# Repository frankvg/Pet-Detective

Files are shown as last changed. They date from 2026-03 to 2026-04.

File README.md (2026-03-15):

Pet Detective monitors pet movement in and out of a pet door, records the action, and logs the time. It uses an ESP32 processor with a Time-of-Flight laser sensor. The software is mostly C++ for Arduino, along with some HTML and JavaScript. See the PDF file for full details and additional software development notes. 
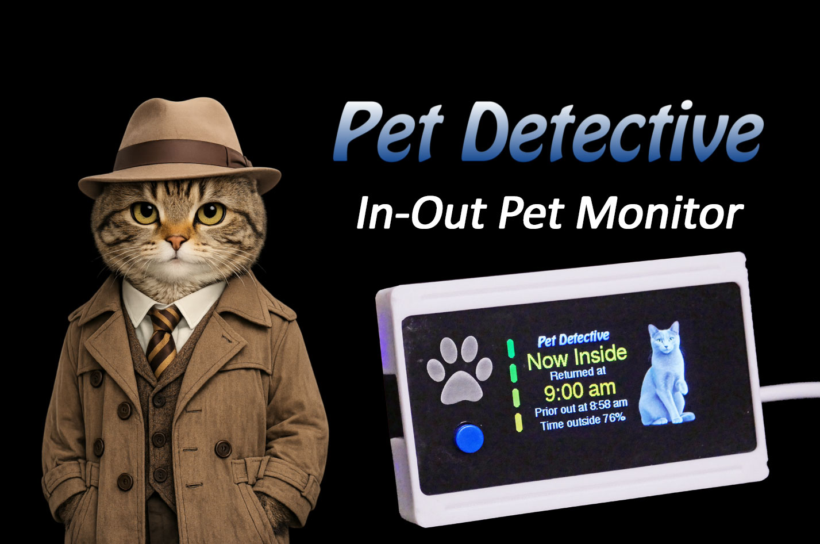
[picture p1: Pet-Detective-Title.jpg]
Model


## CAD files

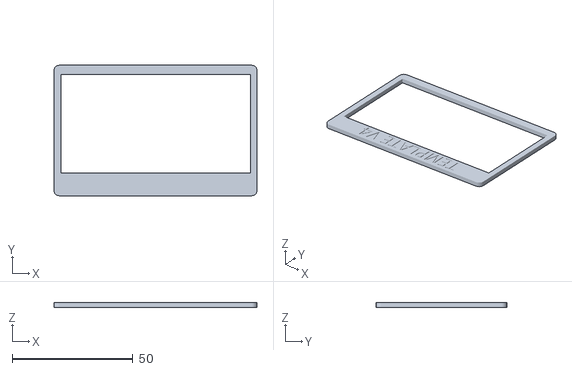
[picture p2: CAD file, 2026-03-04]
3D STL Print Files/Pet Detective Lens Template V4.stl
84.0 x 54.0 x 2.00

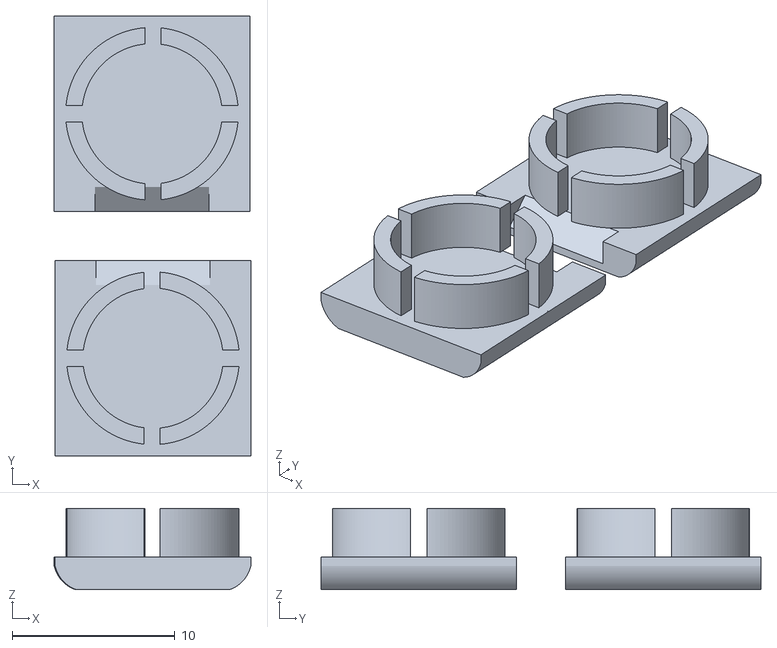
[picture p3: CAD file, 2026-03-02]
3D STL Print Files/Pet Detective HiTech Plug V2.stl
12.1 x 27.0 x 5.00

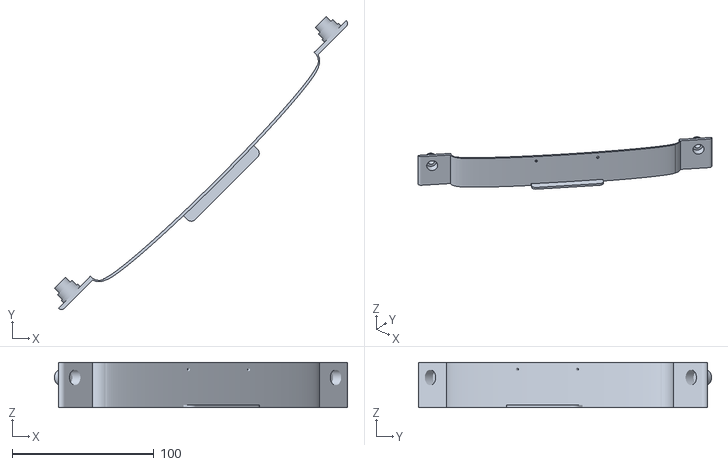
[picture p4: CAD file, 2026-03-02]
3D STL Print Files/Pet Detective HiTech Bracket V3.stl
206.5 x 206.5 x 32.0

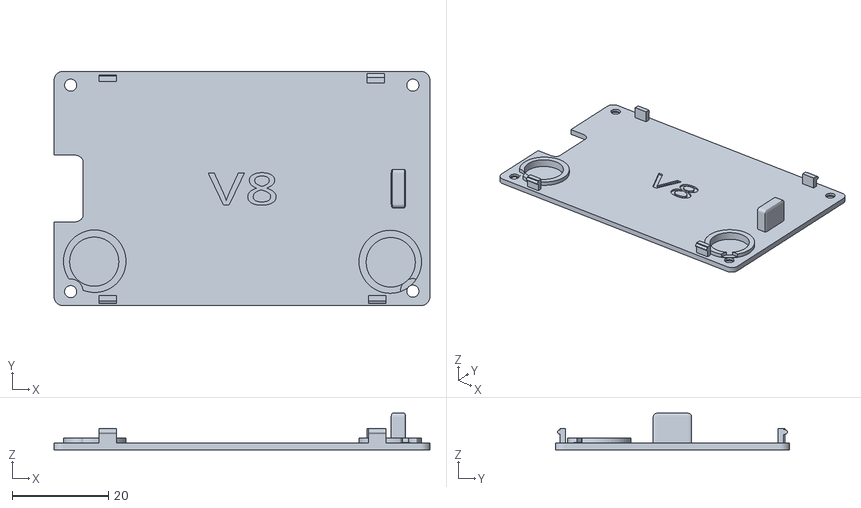
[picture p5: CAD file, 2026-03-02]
3D STL Print Files/Pet Detective Case Back V8.stl
78.1 x 48.7 x 7.60

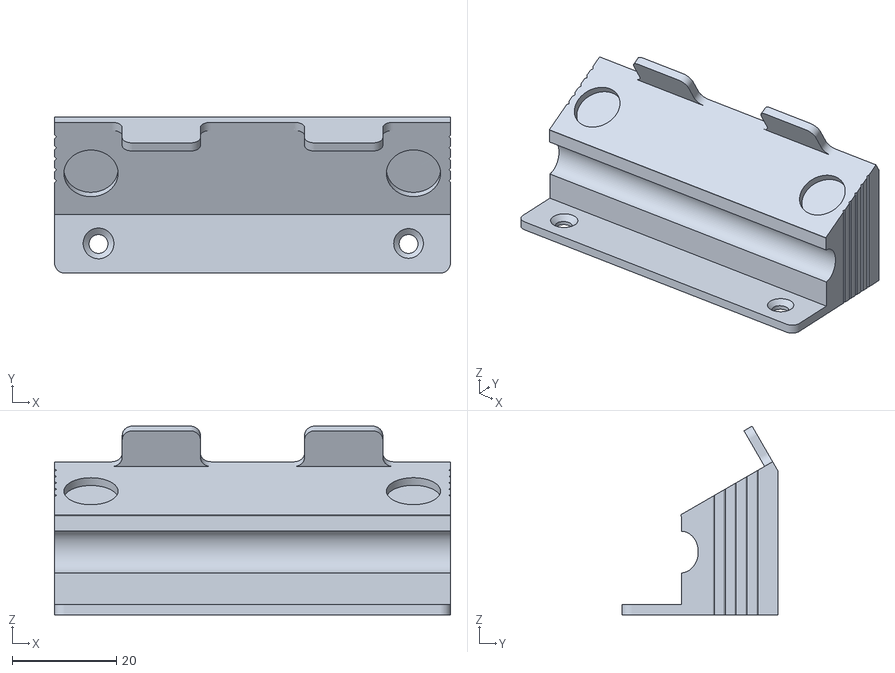
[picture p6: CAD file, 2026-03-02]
3D STL Print Files/Pet DetectiveMounting V5.stl
76.0 x 30.0 x 36.2

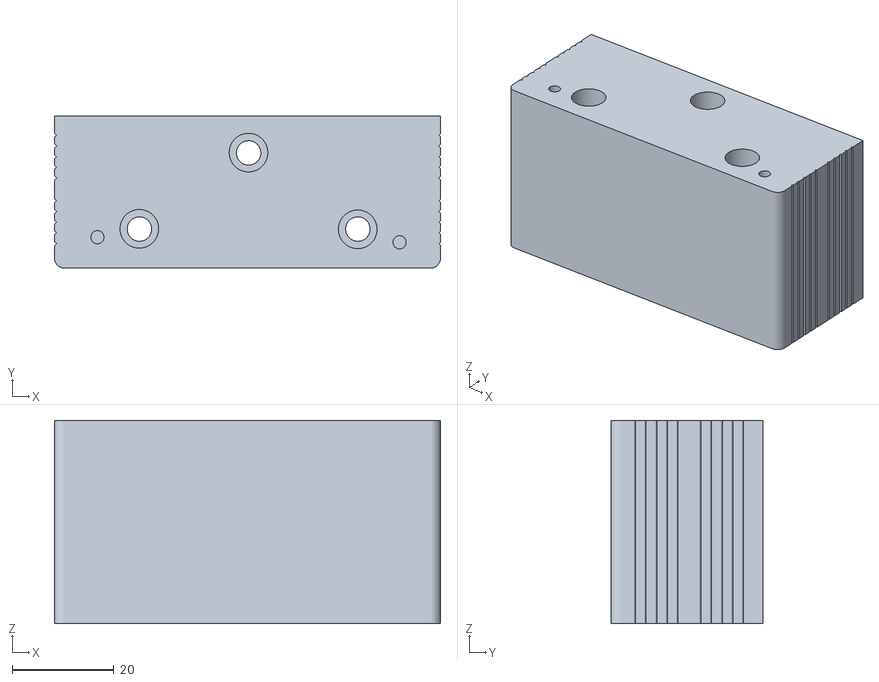
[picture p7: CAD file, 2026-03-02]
3D STL Print Files/Pet Detective Standoff V2.stl
76.0 x 30.0 x 40.0

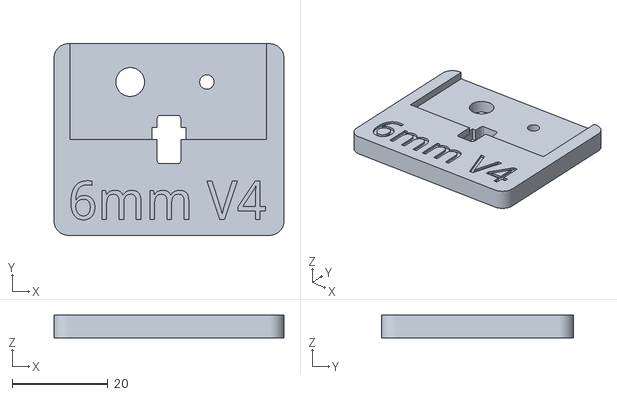
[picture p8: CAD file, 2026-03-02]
3D STL Print Files/Pet Detective Hole Tempate V4.stl
48.0 x 40.0 x 4.80

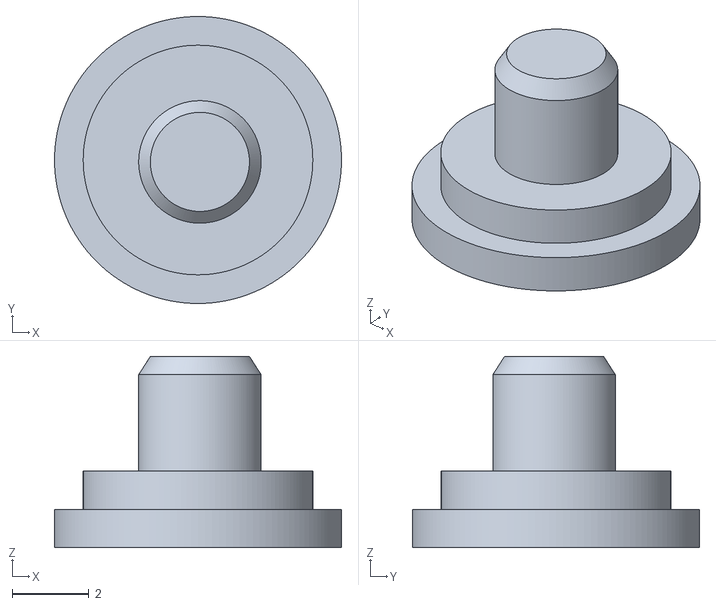
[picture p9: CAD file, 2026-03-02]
3D STL Print Files/Pet Detective Button Bottom V2.stl
7.50 x 7.50 x 5.00

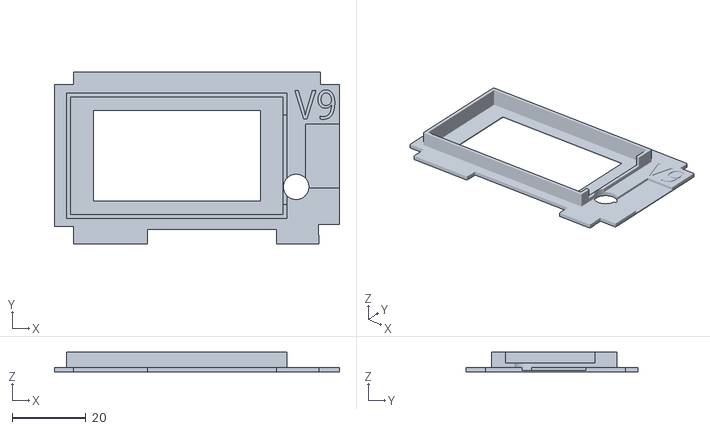
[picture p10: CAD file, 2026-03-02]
3D STL Print Files/Pet Detective Blackout V9.stl
77.4 x 46.6 x 5.40

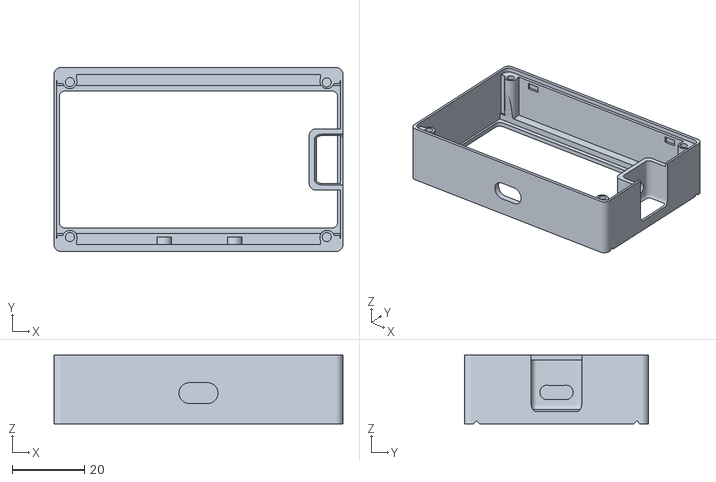
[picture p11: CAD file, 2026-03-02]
3D STL Print Files/Pet Detective Case Front V6.stl
80.0 x 51.0 x 19.0

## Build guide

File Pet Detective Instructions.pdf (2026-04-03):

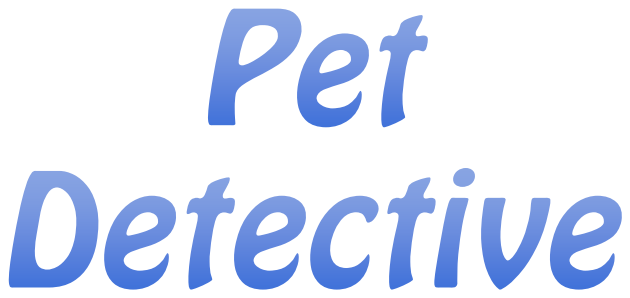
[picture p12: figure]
Pet Detective

Pet Detective tracks your pet’s movement in and out of a pet door. The time your pet goes in or out displays on the monitor and time stamped in a log. The information appears on the unit’s 1.9” LCD monitor.

WiFi is used to get the time and maintain time accurately. Using WiFi, Pet Detective can also display your pet’s status on a browser running on your local network.

## Features

- Location of pet, inside or outside, with time of occurrence
- Percent of time spent outside vs. inside
- View of instant sensor status
- Log of last 32 pet movement directions with a date/time stamp
- WiFi Status and WiFi Reset option
- Automatic time set, even after power failure or DST change
- View the status and log via browser on your local network
- Sensor calibration and distance monitor
- 12 or 24-hour mode selection
- Time Zone setting for 7 North America zones and DST options
- Choice of colors for Inside and Outside status: Green, Blue or Amber
- Select a set of Cat or Dog images

## Video

Video of Pet Detective in action: https://youtu.be/zv0K4LfRqQs

## Skills Needed

This is a rather complex project, but we have done all the hard work in design! You will need to be able to print 3D parts; make or buy the cover lens; solder a few wires; perform simple mechanical assembly; install the software; mount the unit above your pet door; and enjoy!

## Parts List

These are the project parts. You may have parts already in your collection or find other sources for the parts. Substituting alternative parts may require changing the case design or software. Links are for sources we use, but we have no affiliation with any of these vendors. We also made a partial kit of parts to save time and money. Prices were as of April 2026.
Electrical Parts
- ESP32 Dev Module, includes 1.9” LCD display ($16) https://www.amazon.com/dp/B0D6QXC813

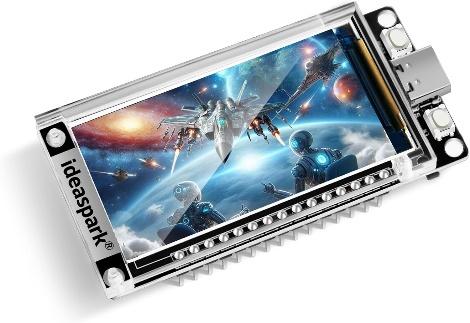
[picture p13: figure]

- VL53L5X V2 8x8 Wide Angle Time-of-Flight Laser sensor module ($17-19) https://www.walmart.com/ip/8565454261 OR https://www.amazon.com/QERPON-Multiple-VL53L5CX-Distance-Measuring/dp/B0F1TFWVNL (https://www.amazon.com/QERPON-Multiple-VL53L5CX-Distance-Measuring/dp/B0F1TFWVNL)
- 180-degree USB C adapter https://www.amazon.com/dp/B0BRFZHJVW ($7 for 2-pack, optional)
- USB C cable (any data cable should work)
- USB power adapter (It requires less than 10 mA, so any adapter will work)
OR
USB Power bank battery – This unit requires so little power, a 7500 mA power bank should power Pet Detective for a month before you’d need to recharge it.

Other Parts

- Hard plastic button (optional, see text, included in parts kit)
- 4 – 10mm diameter x 1mm magnets https://www.amazon.com/dp/B0CZ94J8BS ($8 for 100 magnets)
- 6 – M2.3 x 4mm Flat head self tapping screws (M2.5 x 4 mm ok as well)
- 2 –M3 x 8 mm flat head wood screws (for mounting bracket)
- 2 - M4 x 50 mm round-head wood screws (for optional extended mount to door)
- 1 - Male/Female connector pair with wires (optional, $8 for 10 pairs) https://www.amazon.com/dp/B0DNTK1S9L
OR
4 - 3” (8 mm) 26-28 gauge wires, ideally in 4 colors
3D Printed Parts
- Case angle door mount
- Case front
- Case back
- Cover lens template (not needed for laser cut lens)
- Cover lens hole template

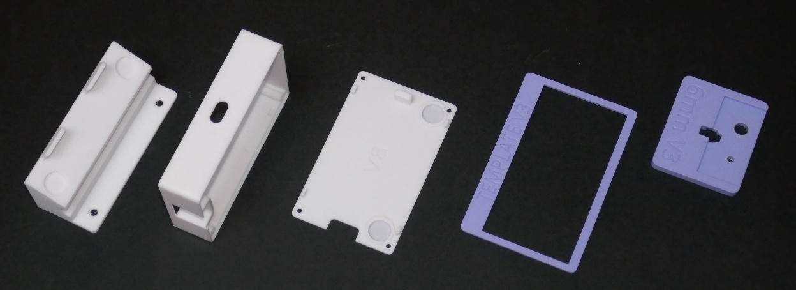
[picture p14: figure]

Door mount, case front, case back, and cover lens template and hole template

- Blackout LCD mask

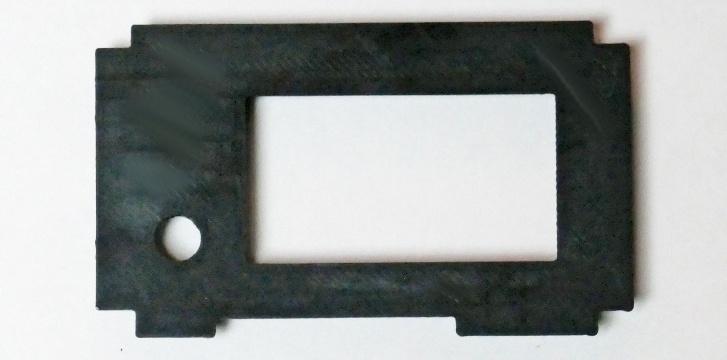
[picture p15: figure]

Blackout LCD Mask front facing
- Printed button holder (black) with injection molded key cap (blue)

Optional 3D Printed Parts

- Extended mount for pet doors that extend out from the door such as OnlyCat Microchip, PetSafe SmartDoor, Sure Microchip Connect, etc.

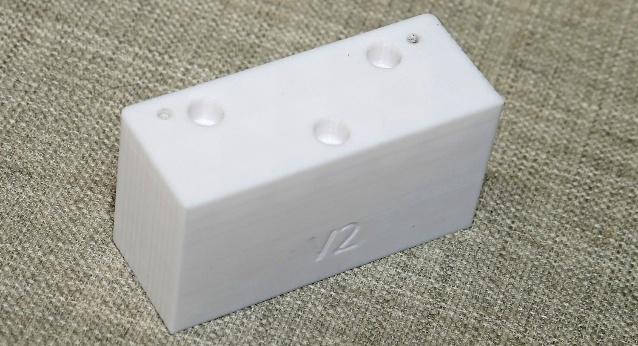
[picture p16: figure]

- High Tech medium size pet door mount and covers (covers not shown)

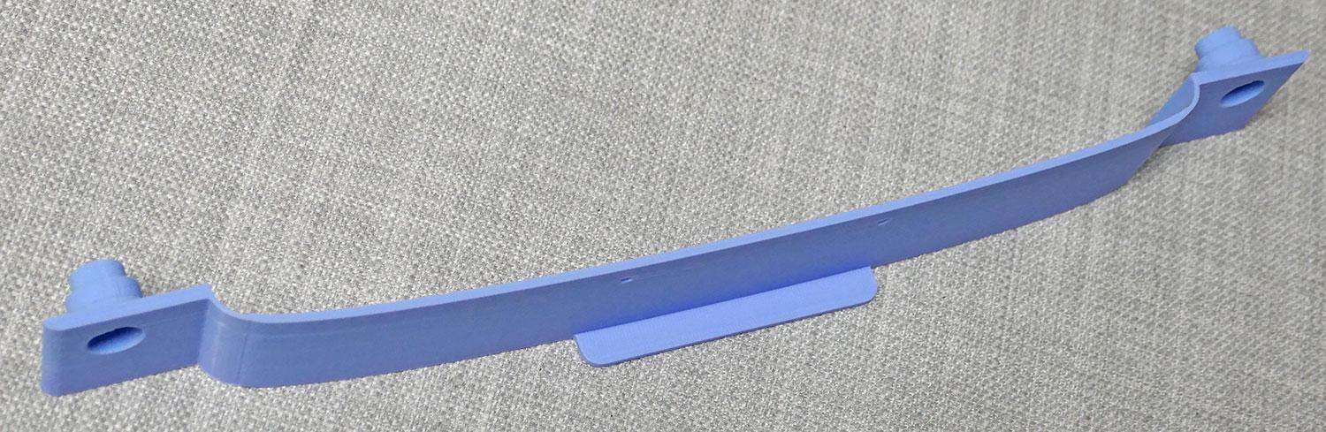
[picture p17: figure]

High Tech pet door mount

Hand cut or Laser Cut Cover Lens
Pick from dark smoke (preferred), clear, or transparent grey.
- 1/16” cast acrylic Dark Smoke Grey #2074, 6” x 12” sheet, ($5 + $21 shipping) https://www.estreetplastics.com/Gray-Smoked-Plexiglass-Acrylic-2074-1-16-p/x-t81060.htm (https://www.estreetplastics.com/Gray-Smoked-Plexiglass-Acrylic-2074-1-16-p/x-t81060.htm)
OR
1/16” cast acrylic clear, 8” x 12” 2-pack ($7)
https://www.amazon.com/dp/B0DW1G8D7K
OR
1/16” Polycarbonate Transparent Grey, 12” x 12” sheet ($8; for manual cutting only) https://www.amazon.com/dp/B09SFC8J56
- Final size – 77.5 mm x 40.3 mm, with 6.3 mm hole

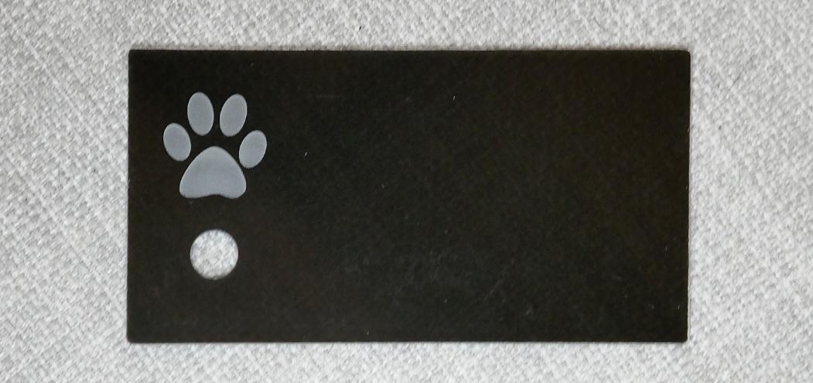
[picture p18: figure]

Laser Cut Dark Smoke Acrylic Cover Lens with Engraved Paw Print

Partial Kit of Parts
We made a kit of select parts to make the project easier and at a lower cost ($23). These kits are available on eBay while supplies last at: https://www.ebay.com/itm/267592151520 This kit includes 2 - M3 x 8 mm screws; 6 - M2.3 x 4mm screws; an injection molded 6mm blue button; 4 - 10mm diameter magnets; a male and female connector pair; and a laser cut lens cover made from smoke transparent acrylic with a paw engraving. You will still need to source/buy/make the other parts.

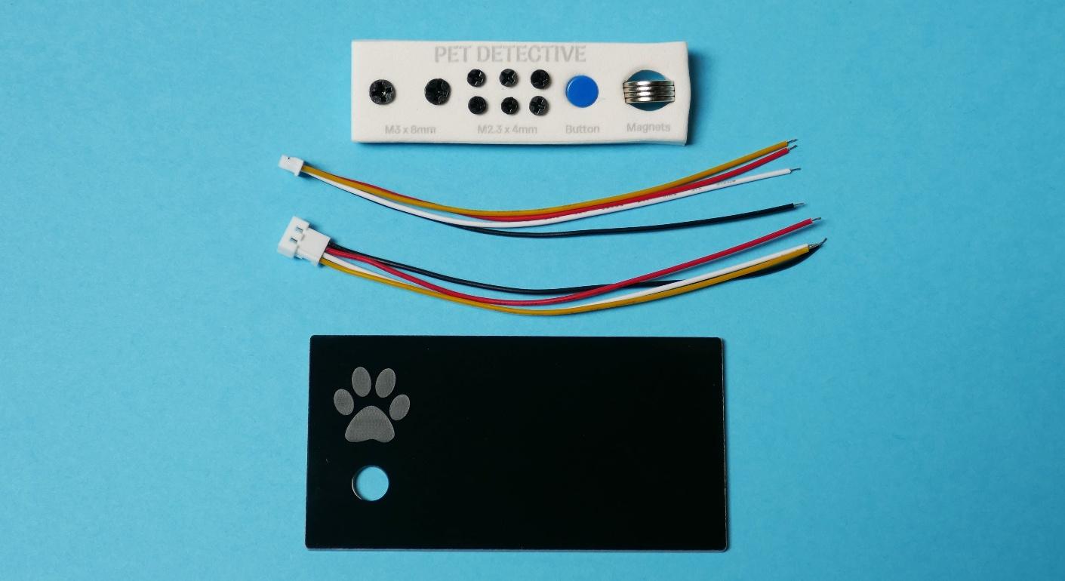
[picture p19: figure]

## Building Pet Detective

Wiring
You can directly connect the ESP32 module to the TOF sensor (4 wires) or use the wired connectors as we did. If using the connectors, only use 4mm / 1.5” of wires from each connector.

On the ESP32 Module, trim the pins down to 2mm. Use diagonal pliers to cut them down. It would have been nice to buy these without the headers, but I never found such a version.

Solder wires from the connector to the processor board:

VL53L5X | Color | Ideaspark | ESP32
Labels | Wire | Pin | Label
VCC | red | 1 (3.3v) | 3V3
GND | black | 2 | GND
SDA | white | 11 | D21 (IC2 data)
SCL | yellow | 14 | D22 (IC2 clock)

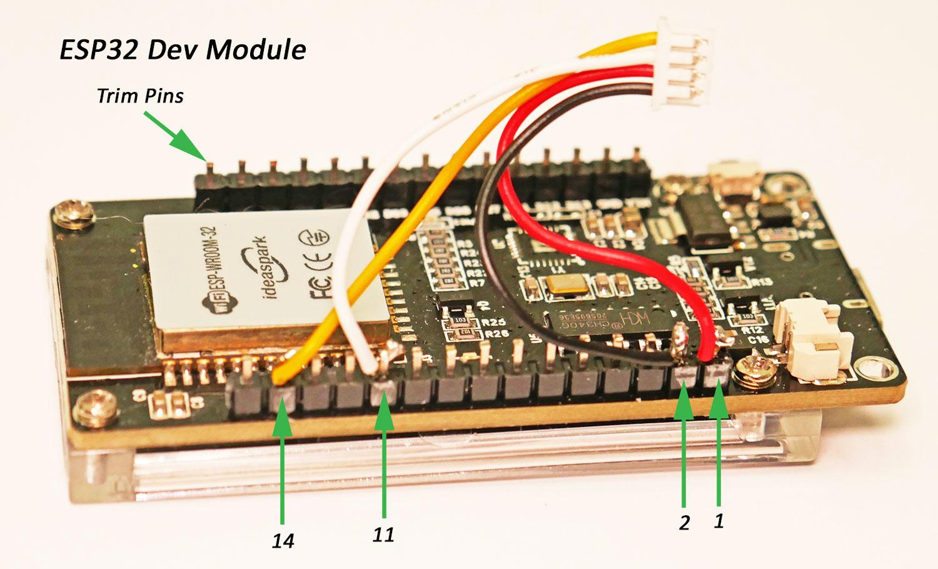
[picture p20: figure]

3D Printed Files
All of the 3D STL print files are located at these two locations:
- https://github.com/frankvg/Pet-Detective/tree/main/3D%20STL%20Print%20Files
- https://www.makeronline.com/en/model/Pet%20Detective%20Location%20Monitor/272746.html (https://www.makeronline.com/en/model/Pet%20Detective%20Location%20Monitor/272746.html)
The Makeronline repository also includes Pet Detector Parts.3mf, with all the parts and settings to print on an Anycubic Kobra S1 printer. This is likely to work with other printers that accept the 3mf file format with minor tweaks.
3D Printing Tips and Notes
We used a smooth build plate. It really improves the case front surface and the blackout frame parts, but it should work fine with a stock rough-surface plate too. The blackout frame should be black. The case and other parts can be any color you want. We tried both black and white, and preferred the white, as it matches our pet door color. We used PLA for all parts, but PTEG or ABS should work fine too. If the Pet Detective case or parts will be in the sun, then use PTEG or ABS.
When printing the case, support is required. I recommend tree supports, and use the advanced support setting for object first layer gap as 1 mm. If you get any mushrooming on the first layers, you will need to adjust the Z axis setting. Typically, negative values push the hotend closer to the build plate (more mushrooming) and more positive value moves it upwards (less mushrooming). A small change can make a dramatic improvement. Button
There is a single button for various functions. I first tried a 3D printed button and even at 0.08 mm layer height, the results were poor. I had some 6mm x 6mm button caps, which were injection molded. There was no flange on the button to keep it captured, so I did print a tiny button flange (0.2 mm layer height is fine), and epoxied it to the button.

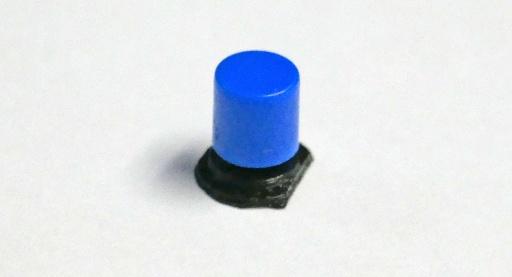
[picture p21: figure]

One side of the flange is missing, so it fits without rubbing on the LCD display nearby.
On Amazon here is a kit of buttons and caps in different colors (far more than needed for this project, and you don’t need the electrical buttons): https://www.amazon.com/OCR-Tactile-Momentary-Switches-Colorful/dp/B07CMZCQS5 AliExpress also has many button choices at a much lower price, but may take a month to arrive. Seach for “button cap 6mm”. Often these are listed as A56 buttons. A button is included in the parts kit on eBay.
Front LCD Cover Lens – Laser Cut Method
A laser offers the cleanest cut in acrylic, but not all lasers can cut transparent material. Do not use polycarbonate, as the fumes are toxic and it usually melts and makes a mess rather than cutting. We used the dark smoke transparent acrylic but clear could also be used. We have links to both materials. You may need a UV laser cutter to cut these materials.
We created a cut dimensions to 77.5 mm x 40.3 mm with a 1mm corner radius in our laser software. We also added an engraved paw print. After cutting, we lightly filed the edges to clean off burs. We ended up not using the laser for the hole, as we were unable to find a setting that didn’t melt it slightly around the hole. We drilled the hole instead (see the Fit and Drill section below)

Front LCD Cover Lens – Manual Method
From sheet of acrylic or polycarbonate, cut a rectangular part 77.5 mm x 40.3 mm. Leave the protective film on until the very end to avoid scratches. There is plenty of material if you miscut it to try again. Use the 3D template to help check the size as you cut. After cutting, we filed the four corners slightly, as the corners are sharp!
Front LCD Cover Lens – Fit and Drill
Test the fit in the 3D printed case front. It is expected to be a tight fit and a slight bit of flexing is necessary to snap it into place.

Remove the cover lens to add a 6.3 mm or 1/4” hole for the button. We created another 3D printed template to help position the hole. Position the template over the side of the cover. First drill the small pilot hole 3mm or 1/8”.

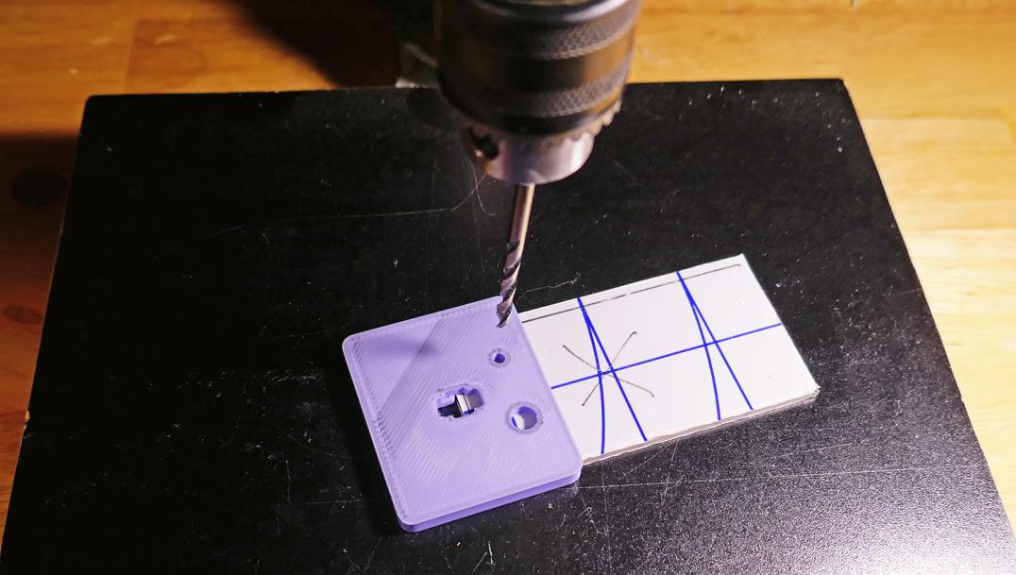
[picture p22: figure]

Using a drill press for the first 1/16” hole Flip the lens in the template and then drill the larger 6.3 mm / ¼” hole into the prior pilot hole. Ideally use a drill press and slowly lower the bit into the hole. If you lower too quickly, it can melt and/or catch and spin it around! Confirm the button fits in the hole without binding and enlarge with a round file if needed. Remove the film and clean any dust and debris with a soft cloth.

Magnets
The magnets are in a roll. To separate the magnets slide them apart. Lifting apart might break the magnet! Using a Sharpe pen, we recommend marking one side with a dot as you separate each magnet. This will help you keep the proper orientation with the “dot” side facing into the plastic. The magnet orientation between the parts is critical, as you need them to attract them rather than repel!
In the back cover insert the two magnets. Use disposable gloves to avoid getting epoxy on your hands and add some epoxy on the top to ensure they stay in place and are electrically isolated from the ESP32 module.
On the case angle mount, first check that the magnets dry fit. If they are too tight, clear away any filament overhang. Carefully put a small amount of epoxy in each of the two indentations. Press the magnets into the epoxy.

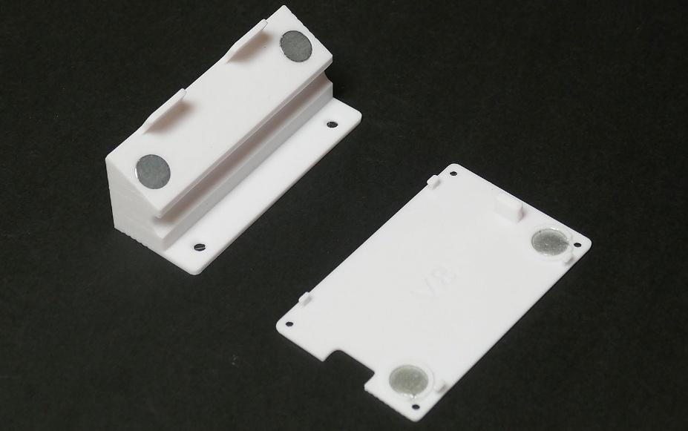
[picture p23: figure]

Magnets Installed on Mount and Rear Case Assembly Order

- Insert the cover lens (some bending is required). The hole is oriented towards the two sides that have holes.
- Insert the blackout frame. It slides under the USB indent.
- Insert the button cap and confirm it moves smoothly.
- On the laser sensor, be sure to remove the clear protective film. Attached the dark red lens cap on the sensor that was included with the sensor purchase. Insert the sensor assembly into the bottom hole and use two M2.3 x 4mm screws to hold it in place.

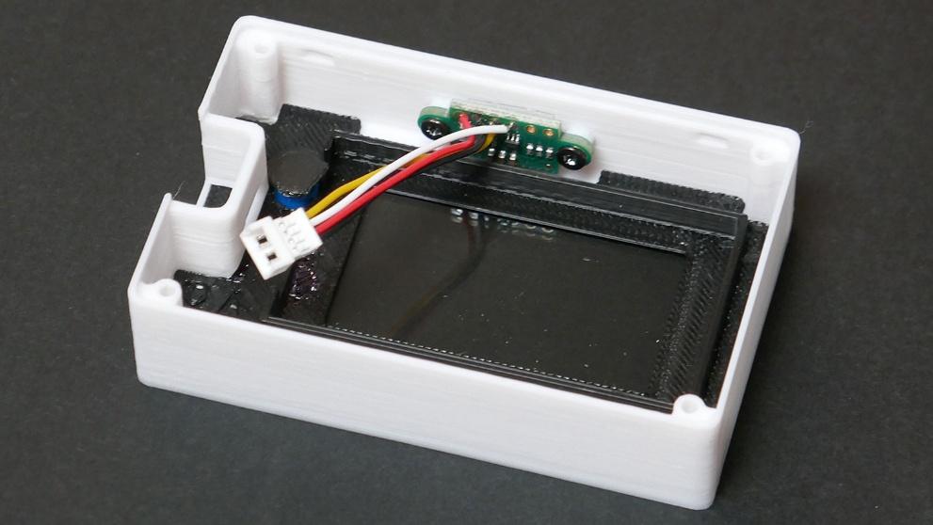
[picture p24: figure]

The assembly with laser sensor installed
- Remove the protective film from the LCD. Slide the ESP32 module USB connector into the hole and press down so the blackout frame aligns it.
- Confirm the button cap smoothly presses on the ESP32 push button.
- Connect the laser sensor connector to the ESP32 connector (each previously soldered).

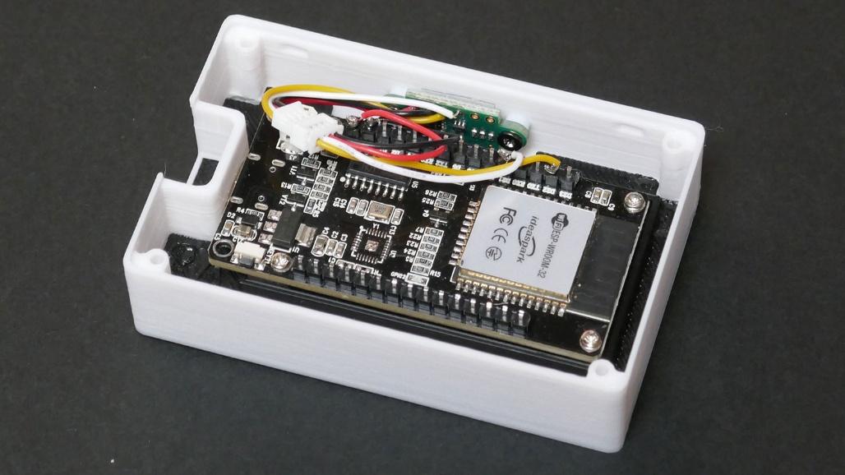
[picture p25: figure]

Sensor and Processor with LCD installed
- Attach the case rear. It should snap into place and is designed to hold the ESP32 in place. Insert the four M2.3 x 4 screws to secure the case.
- Install the 180˚ USB-C adapter (optional). This is not necessary but makes a cleaner look rather than the USB cable sticking out the side, especially if you want the cable to feed out the right side.

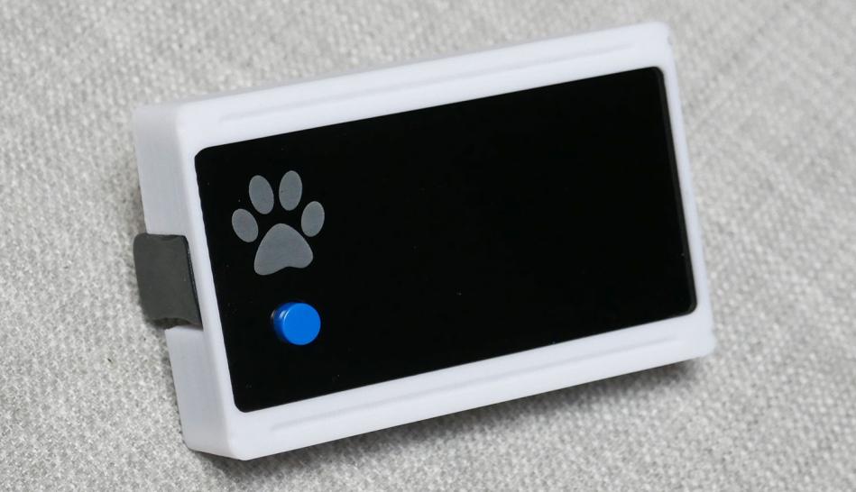
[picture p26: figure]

The Final Assembled Unit

## Software Installation

You will need to download and install the Arduino IDE. Here are detailed instructions: https://support.arduino.cc/hc/en-us/articles/360019833020-Download-and-install-Arduino-IDE (https://support.arduino.cc/hc/en-us/articles/360019833020-Download-and-install-Arduino-IDE)
Next, install the Windows CH340 driver and set up the IDE to work with the ESP32. Follow steps 1 through 8 on this reference: https://manuals.plus/asin/B0D6QXC813. While the driver instructions suggest using Window 10, I’ve had no problems with Windows 11. We have no idea if this can be made to work with a Mac but suspect it can.
Download the Pet Detective source code. It is available on GitHub: https://github.com/frankvg/Pet-Detective
Copy all the files into a directory like: Pet Detective
In the sketch_pet_detective directory, double-click on the file: sketch_pet_detective.ino The IDE should open with the needed files.

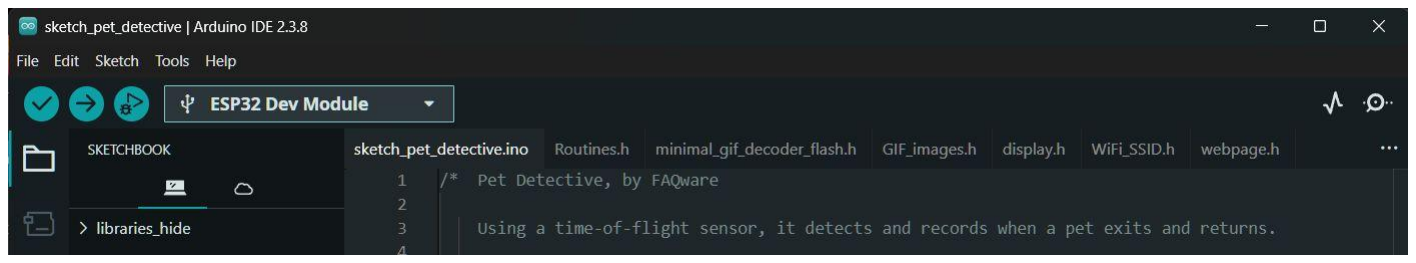
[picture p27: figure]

Connect the ESP32 module via USB to your PC. Check and/or set the COM3 connection in the IDE from the menu: Tools -> Port
With things set up properly, the Tools menu looks like this:

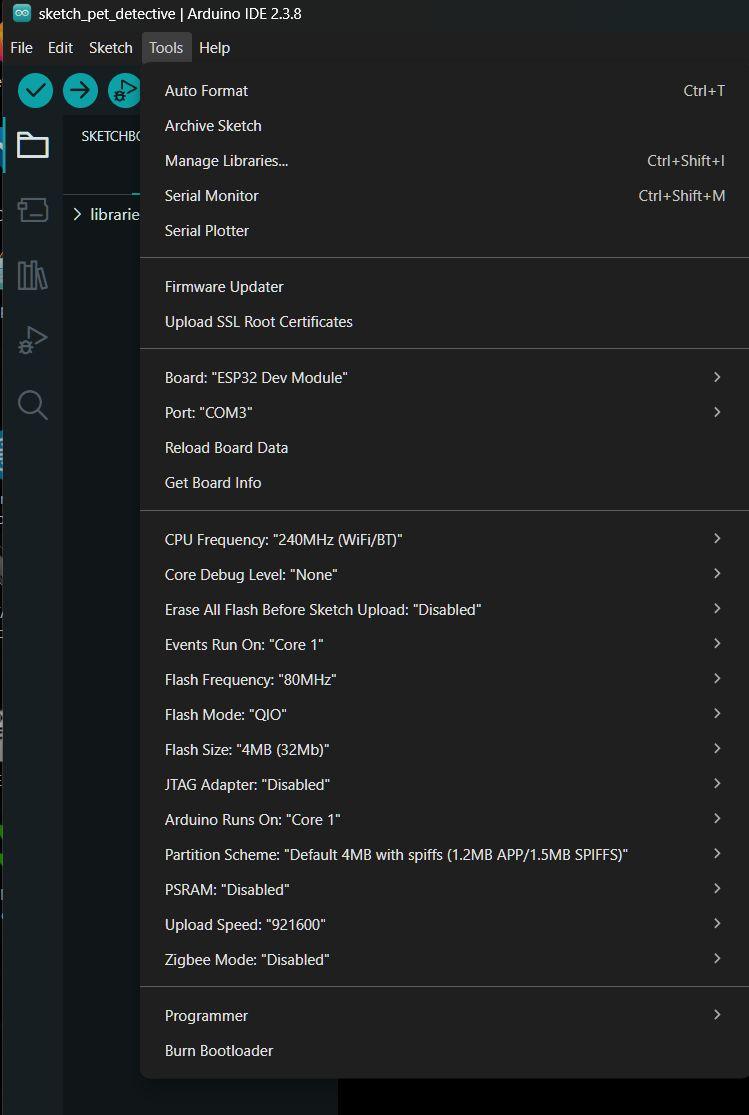
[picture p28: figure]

On the Tools menu, select Serial Monitor. If you get the amber error:

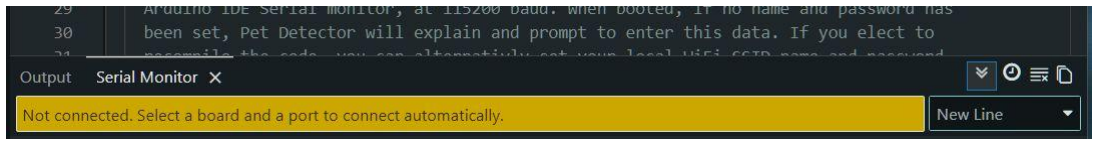
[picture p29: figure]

Something is not set up right and you’ll need to resolve it. One common error is using a USB cable that is power only (no data). The Serial monitor should be set to 115200 baud. Select the download button (see the hand icon below) to compile and install the software into the ESP32 module.

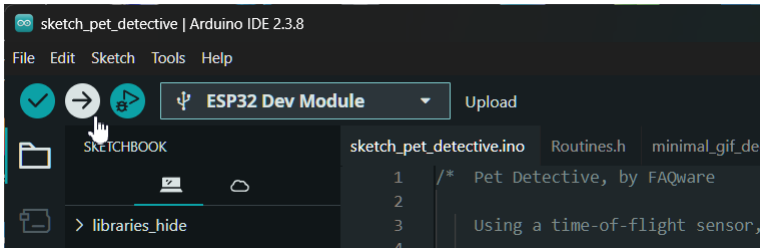
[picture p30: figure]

When properly connected and booting for the first time, in the Serial monitor you’ll see it ask for the WiFi SSID and password:

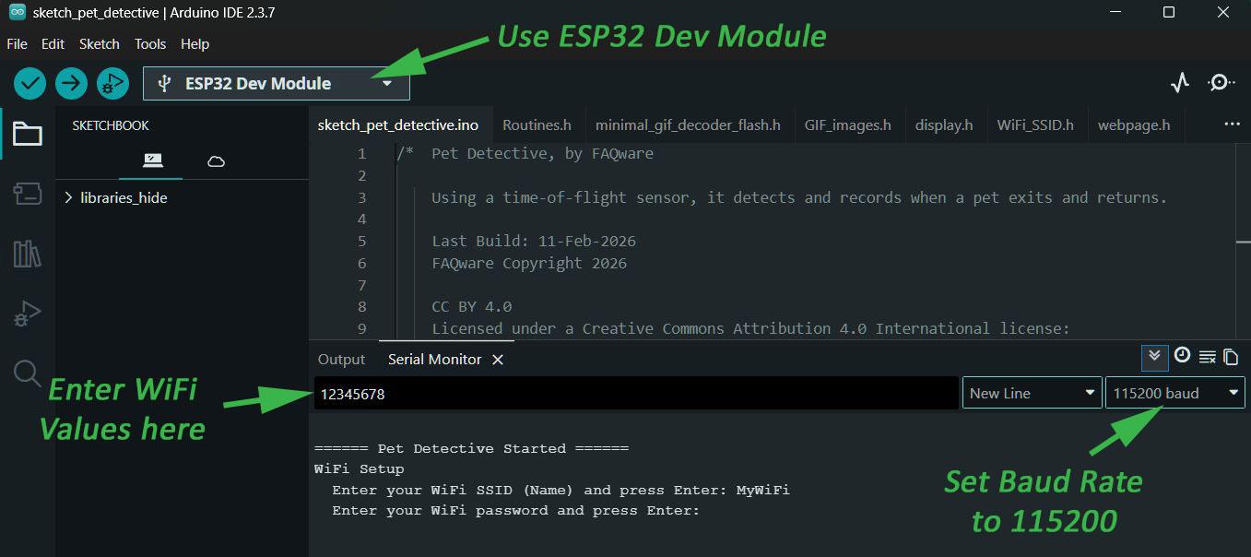
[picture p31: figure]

Enter your WiFi information when requested or press Enter twice if you don’t plan to use WiFi. Once set, the data is remembered and will not ask again. If you need to enter or change it later, when Pet Detective is installed and running, use short button presses to get to the About menu, and long press (10-seconds) to do a factory reset. With a reset, the WiFi data is cleared, and the IDE Serial Monitor will prompt again for the SSID and password. As an alternative, you can also hard code the SSID and password in the WiFi_SSID.h file.

## Mounting Pet Detective

The Pet Detective case must be installed above the pet door at a 30-degree angle, so the laser detection covers the area in front of the pet door. The case angle mount provides the 30-degree angle needed. This also makes the display easier to see.

The mount must extend out so that the first downward facing laser detection beam is in front of the door. This image shows a side view with the combination of the extended mount, the case angle mount and the Pet Detective case.

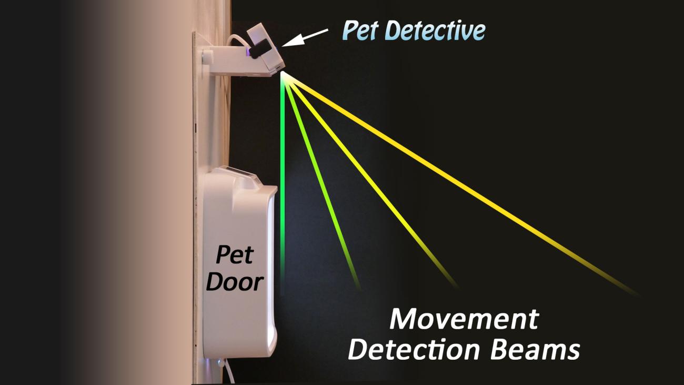
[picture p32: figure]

Side View Laser Angles with Extended Mount Other pet doors may not need the extended mount and/or may need a different mounting. If you do need a different extension size, it is easy in your slicer to change the Z size to something different.
If you have the medium size High Tech pet door, we made a bracket that holds the Pet Detective on existing holes in the Pet Door. The design includes two screw hole covers. We happen to print these in blue PLA. The extended mount is not used.

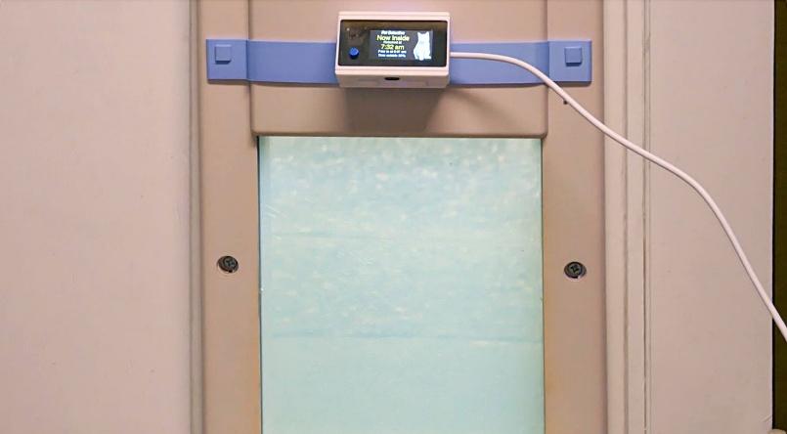
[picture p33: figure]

## Using Pet Detective

To test Pet Detective, you only need to move your hand forward or backwards under the sensor. You will see color bars on the left showing when each laser detector triggers. After each detected transition, we have a 12 second transition lockout. We found this avoided duplicate transitions when a pet moves slowly.
Menus
A short press of the button will rotate through the various menus. While in menu mode, it will not detect pet transitions. If left in a menu, after 5 minutes of no activity, it will revert to normal monitoring mode. Settings, other than time and log entries, are saved in non-volatile memory.
Log – This shows the last 4 transitions. You can rotate through the 8 pages of the log with a long (1 second) press. It shows the date and time of each transition, along with trend data. Every 100ms, we count trends of laser threshold detection in each direction to help determine a valid transition.
WiFi – Shows the SSID you set, the MAC address, the web address to remotely monitor status and log data, and the signal level. A long press in this menu is used to reset WiFi and reacquire the time. Ideally signal strength should be -30 to -50 dB. At -60 dB or worse it may not be able to get the time, and web access will be painfully slow.
Sensor – Shows the distance detected in millimeters for each of the four laser detectors. It also shows the current sensor threshold. Use a long press to recapture a new threshold value. Threshold is set at 60% of the shortest distance measured on the four laser detectors. If you are getting erratic transition results, changing the threshold often makes a dramatic improvement.

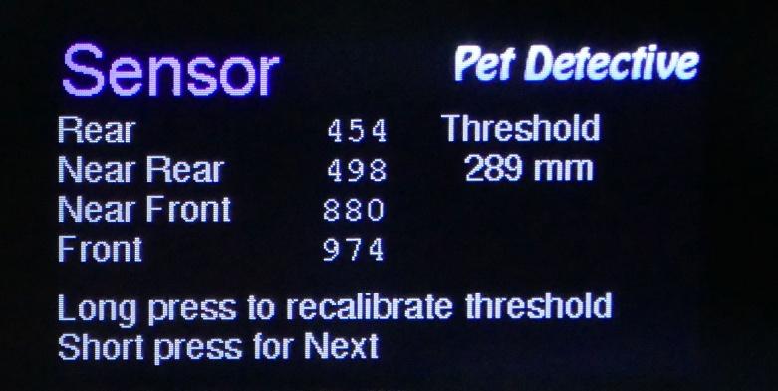
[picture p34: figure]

Once a threshold is set (either from this menu or the very first time powered up), it is retained in non-volatile memory. All later power-up sequences will use the saved threshold value.
Hours – Use a long press to toggle between 12-hour and 24-hour time.
Time Zone – Use a long press to switch to the next time zone and DST (Daylight Savings) mode. The time will be updated immediately on the display. We support time zones from Hawaii Standard Time (UTC-10) to Atlantic Standard time (UTC-4). A code change will be needed for other time zones.
Color – There are 3 colors in 6 combinations. Each long press toggles through the 6 combinations. A very long 10-second press toggles the brightness. The default is maximum brightness, intended for the dark smoke acrylic lens. If using a clear or light polycarbonate lens, the dimmer setting with improved color vibrance may be preferred.
Pet Images – Toggle the current set of pet images between cats and dogs.
About – Basic information. A very long 10-second press resets all values to factory defaults. This also clears the WiFi name and password. Use the IDE’s serial monitor to enter a new name and password when prompted. A short press ends menu mode and returns to normal transition monitoring.

Transition Accuracy
If your pet leaves or returns when not going through the pet door, Pet Detective will not be aware of the change. We sometimes let our pet in through a nearby door. If wanted, you can sweep your hand under the sensor to set a fake “Now Inside” status.
We’ve also had a few rare occasions when the pet is inside, he comes up to the door, looks out, but doesn’t exit. Depending on the angle and how they move, it could trigger a gone outside transition when he is still inside.

Browser
Using the URL from the WiFi menu, you can view the status and the full log in any browser on the same local network as Pet Detective. Note that you must use a http:// prefix, and not https://. Most new browsers will automatically switch to https://, which will then give you an “Unable to connect” error. If this occurs, do a Google search for “option to allow http://” for your browser and follow the instructions. Heres’ an example with the status and log view enabled:

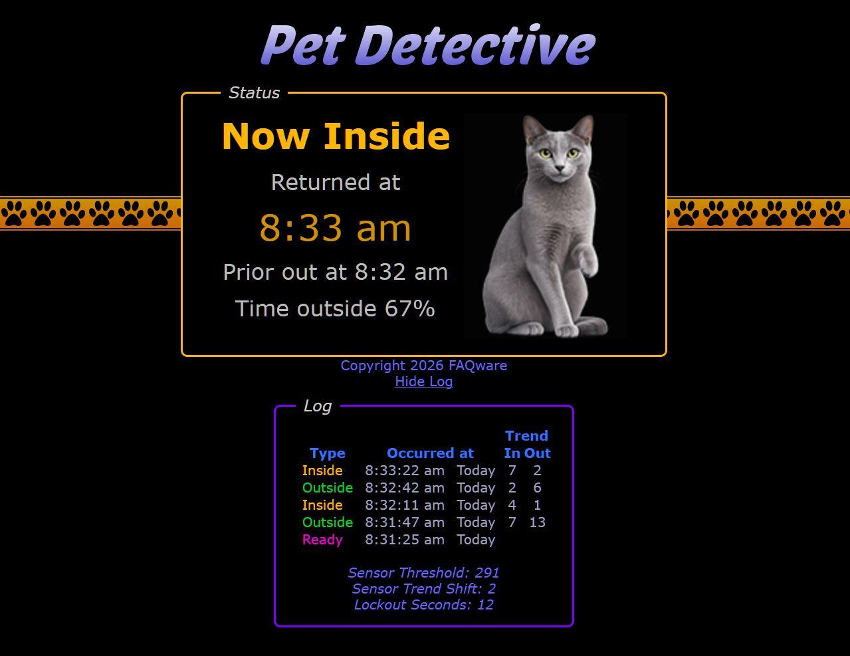
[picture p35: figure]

Status changes are checked every 6 seconds. Web page updates are ignored when you are in a menu. When processing a web page or checking if a change occurred, a small light-blue dot appears in the bottom-right corner. In most browsers, when the web page is hidden (i.e., not an active tab), the JavaScript stops running and updates do not occur. Once the page becomes active, it should update within 6 seconds.

## Troubleshooting

Button - Failure to reliably detect button presses can occur if the processor is a bit overloaded. Updating the web page on your local network, going out to the internet to get the time, or transitioning the display can each take far more than the allocated 100ms loop time, causing a short button to press to be ignored.
Fails to detect pet transition – In almost all cases the sensor threshold is set too short. When booted it shows the saved threshold. You can also view the threshold in the Sensor menu. Reset the threshold from the Sensor menu. A good value is the distance from the sensor to a depth about ½ below the top of the pet’s body.
Duplicate pet transitions – These are tricky to fix if you have the sensor threshold set properly. Be aware if your pet comes up to the door, waits, and then leaves without making a transition through the door, it may trigger a duplication. This can also occur if your pet is either let out or in through a different door, so a transition state is missing.
Look at the sensor trend data to see if a different sensor trend shift might help. This can only be changed in the source code and really shouldn’t be necessary.
No Time and/or Slow to no Web Page updates - This usually indicates a weak or no WiFi access. Go to the WiFi menu and check the signal strength (two short presses). Ideally the signal strength should be in the -50 to -40 range or better. A signal strength of -60 or worse does not provide enough bandwidth to do much.

## Notes for Software Developers

Pet Detective software consists mostly of Arduino C++ for the ESP32 processor. It also includes some HTML for the web page, and a small amount of JavaScript to only perform web page updates when a transition occurs.
Graphic Images
Graphics for the four pet photos are small GIF images, which are saved as byte data in program memory. If you wish to replace a GIF image, you will need to make the non-animated GIF (the same size as we use), 256 colors, and use a black background. Turn off transparency. Convert the image into an array of bytes for C++ and replace the existing array for that graphic. Here is the online GIF to File array converter we use: https://mischianti.org/online-converter-file-to-cpp-gzip-byte-array-3/
The code will decode the GIF content into a displayable format for the LCD (RGB565 pixels). The cat image byte arrays are stored in GIF_cats.h as:

Startup: | 141 x 140 | Cat_Detective_Jacket_141x140.gif
Ready: | 123 x 170 | Cat_Ready_123x170.gif
Inside: | 123 x 170 | Cat_Inside _123x170.gif
Outside: | 123 x 170 | Cat_Outside_123x170.gif
The dog image byte arrays are stored in GIF_dogs.h as:
Startup: | 141 x 140 | Dog_Detective_Jacket_141x140.gif
Ready: | 123 x 170 | Dog_Ready_123x170.gif
Inside: | 123 x 170 | Dog_Inside _123x170.gif
Outside: | 123 x 170 | Dog_Outside_123x170.gif
We realize this is a bit complex to change an image, but it is necessary as the ESP32 module has no SD Card or file system to store a GIF file. The ESP module is also a bit slow, so we suspect if an SD card and file system were included, it would be far slower than having the data already in program memory. We did test pre-loading the images in RAM but didn’t notice a significant difference in display performance. Generally displaying one of the four pets above takes about 1 second to display. A one-second update is not an issue, as the display changes infrequently and only after a transition occurs.

Sensor
We use a Time-of-Flight IR laser sensor that can detect the distance of 64 different locations over a 60x60 degree spread. We only use the faster 4x4 mode (16 locations), and then only look at 4 of these locations. When the module is powered on for the first time, it does an automatic calibration, assuming it is installed and has no pet in sight. This is saved and used from that point onwards. The software limits the distance threshold to between 300 mm and 80 mm. Even if you were blocking the sensor during calibration, it’s likely close to what works anyway.

The sensor menu allows you to view the real-time sensor distance measured in millimeters. From this menu, you can also reset the sensor threshold. Once the threshold is set, either at the very first-time boot, or manually from the sensor menu, it is saved and does not change in future power/boot cycles.
A “secret” trace menu is available on the Sensor menu by holding the button for 10 seconds. It shows all the data collected for a single transition. Every 100ms, each of the four triggered sensors are shown in a log of values in a single screen. When one full transition cycle is completed, it shows the Trend values and if it is a Inside or Outside transition, based on the Trend shift value. We used it for tuning the design.

WiFi
Pet Detective uses WiFi to obtain and maintain the current time. It will work fine without WiFi, but it will not be able to time-stamp events. To use WiFi, during connection to the IDE, during the first powerup, you will be prompted to enter your WiFi name (SSID) and password. Optionally, if you plan to recompile, you can hard code WiFi info in the WiFi_SSID.h file.
The ESP32 module has a built-in antenna on the left side. It does require a good signal, so if your WiFi router is too far away and/or has too many walls between it and the Pet Detective, you may not be able to make WiFi work.
Security
Pet Detective does so little, there is no need for web site encryption. Should someone hack your local WiFi network, they might see if your pet is inside or outside If they happen to connect during the few seconds when a transition occurs and you are looking at the web page.

There are no remote downloads into the ESP32 nor other ways someone could hack Pet Detective. Web encryption (https://) would slow web page display considerably, as the ESP32 processor is not intended to be a powerful server. As it is, the simple Pet Detective server sending a full web page, with log, consumes 1 to 2 seconds of processing time. This doesn’t cause a problem as the web page is only updated during a pet transition during the 12-second lockout period.
Pet Detective goes to the internet to get the date and time. There is no code in Pet Detective to go to any other server or external connection.

We default using the most common time reference: pool.ntp.org. You are welcome to change it to any other standard NTP server in the code. Should the time server fail to provide the time, Pet Detective tries again later. Once the time is acquired, it checks periodically to accurately maintain the time. If you have a power failure, it automatically acquires the time upon power up.

## Options and Future Enhancements

Phone/Tablet Status
You can access Pet Detective’s web page when the device is connected to the same local WiFi network. On Android, we use a widget WebsiteWidget by Orbit Knot to display the Pet Detective Status in a 3x2 widget. It does a great job, but be aware updates only occur every 30 minutes or so (as of March 2026).

Sound
We are considering adding an amplifier and small speaker to create a sound for incoming and outgoing events. The ESP32 module does not have an output that can drive a speaker directly, so an extra amplifier is needed. Since there is no file system, it also means the WAV file needs to be converted into a large byte array. There may not be enough remaining code space to include such a feature.

Version 1.6 © 2026 FAQware

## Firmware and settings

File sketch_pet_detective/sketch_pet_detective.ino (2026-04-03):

/*  Pet Detective, by FAQware

    Using a time-of-flight sensor, it detects and records when a pet exits and returns.

    Last Build: 31-Mar-2026
    FAQware Copyright 2026

    Licensed under a Creative Commons Attribution-NonCommercial 4.0 International Public
    License
    https://creativecommons.org/licenses/by-nc/4.0/legalcode.txt

    The design uses 4 IR lasers and sensors to detect the motion of the pet across the four 
    sensors. The direction across the sensors determines which direction the pet has gone.  
    Sounds simple, but pets don't move as reliability as one hopes. The pet may come to the 
    door but not actually leave. They may leave or enter from the side angle. The sensors 
    cover 60-degrees and are spaced out in 15-degree increments perpendicular to the door. 
    The first beam is straight down (as the 3D printed case is designed to tilt the module 
    30 degrees).

    Our trend analysis of movement and with some weighting, gets fairly accurate. 
    We also auto-calibrate distance to the pet when first powered, and this is easily re-
    adjusted. You can go to the Sensor menu and see the distance (in mm) that each sensor 
    is detecting and recalibrate if needed. We also have a lockout period to avoid false 
    duplicates, currently set to 12 seconds.
    
    All user settings, including the distance calibration, are restored after a power
    failure. Logs are not saved. WiFi is not required but is used to set and maintain 
    accurate time. Your WiFi name and password can be entered and saved while using the
    Arduino IDE Serial monitor, at 115200 baud. When booted, if no name and password has
    been set, Pet Detector will explain and prompt to enter this data. If you elect to
    recompile the code, you can alternativly set your local WiFi SSID name and password 
    in the file “WiFi_SSID.h”. If WiFi is not used or detected, transtion status appears 
    without time information.

    A bonus with WiFi is you can use any local web browsers to see the transition status 
    by entering the IP address assigned to Pet Detector. There is an option to see all 32
    log entries along with trend values, which can be helpful if you need to further tune 
    the thresholds for your speciifc pet and pet door. IMPORTANT: This only works for
    your local network, and you must use http://  (Not https://).  Browsers often change
    the http to https and then you'll get a "Unable to connect" error.  The full URL
    is shown on the WiFi menu (two short button clicks).

    If you are getting incorrect in/out transition detections, it is usually due to the 
    sensor threshold (distance) set wrong. You can see the actual values in the Senor 
    menu and reset it to a new value. It uses 60% of the shortest distance of the four sensors. 
    It should be set when there is no pet in view of the sensor. The maximum sensor 
    range is limited 300 mm in software.
*/
const bool debug = false;  // false for normal operation
const char version[] = "1.6";


#include <WiFi.h>                       // external libraries
#include <time.h>
#include <NTPClient.h>
#include <EEPROM.h>
#include <Wire.h>
#include <SparkFun_VL53L5CX_Library.h>
#include <base64.h>

#include "WiFI_SSID.h"                  // for your personal WiFi SSID and Password
#include "display.h"                    // various LCD display routines
#include "minimal_gif_decoder_flash.h"  // converts gif data to display on-screen
#include "routines.h"                   // EEPROM and other routines
#include "webpage.h"                    // web page - JavaScript and HTML

int  checkForButton(int pin, int wait);
void frameReady();
void frameInside();
void frameOutside();
void frameLog();
void frameWiFi();
void frameHours();
void frameGmtAdj();
void frameSensor();
void frameColor();
void frameAbout();
void frameError();
void frameWiFiReset();
void frameWiFiSetup();
void frameTrace();
void exitState();
void setState();
void setColorType();
int  InOutLogPtr(int newest);
int  percentInOut();
void showIndicator(int y, int barColor, bool* showing);
void hideIndicator(int y, bool* showing);
void buildIndicatorColors();
void processWebRequest();
void convertWiFiInfo();

String getQueryParameter(String& url, const String& paramName);


/*------------ Time of Flight VL Connections ---------------------------
Item  STEMcolor MyColor Ideaspark ESP32
      wire      wire    Pin       Pin
VCC   red       red     1 (3.3v)  3V3
GND   black     black   2         GND
SDA   blue      white   11        D21   (IC2 data)
SCL   yellow    yellow  14        D22   (IC2 clock)
*/

SparkFun_VL53L5CX myImager;
VL53L5CX_ResultsData measurementData;  // Result data class structure, 1356 byes of RAM
int imageResolution = 0;               //Used to pretty print output
int imageWidth = 0;                    //Used to pretty print output

bool sensorValid = false;
int sensorThreshold = 0;        // when booting, assumes furthest distance/2 is the threshold for pet detection
bool indicatorOn[4] = { 0 };    // this for the four side sensor indicators
int indicatorColor[4] = { 0 };  // outside to inside colors (built by buildIndicatorColors)
int sensorAllOn = false;

int tracePosition = 9;
bool showTrace = false;      // true when at least one threshold exceeded
bool endGroupTrace = false;  // after end of threshold indicators, display vertical line
int sensorColumn = 1;        // which of the 4 columns of sensor data to highlight in trace
int columns = 1;             // number of columns to process in Trace mode
int displayLine = 0;         // line to display on trace
int lockoutSeconds = 12;      // ignore events less than x seconds apart


//---------------- WiFi, Web Server & Time ------------------------------------------
int wifi_timeout = 0;
WiFiServer server(80);
int webColor = 0x00CCFF;       // color sent for web page status
bool webShowLog = false;       // show log in web page
int webIndicatorTimeout = 0;   // used to display web processing indicator
String displayNowAction = "";  // text strings for web page
String displayCurrentActionHead = "";
String displayCurrentAction = "";
String displayPriorAction = "";
String displayPercentAction = "";
String displayTrendInside = "";
String displayTrendOutside = "";
bool fetchRequest = false;
bool skipPageUpdate = false;


int time_timeout = 0;
const char* ntpServer = "pool.ntp.org";  // Or pick another NTP server
long gmtOffset_sec = -8 * 60 * 60;       // Adjust for time zone offset from GMT
int daylightOffset_sec = 3600;           // Adjust for daylight saving time if applicable
WiFiUDP Udp;                             // A UDP instance to let us send and receive packets over UDP
NTPClient timeClient(Udp);
WiFiUDP ntpUDP;
time_t now;
tm timeinfo;
const char* monthsOfTheYear[] = { "Jan", "Feb", "Mar", "Apr", "May", "Jun", "Jul", "Aug", "Sep", "Oct", "Nov", "Dec" };
const String zoneAbbreivations[] = { "HST", "AKT", "PST", "MST", "CST", "EST", "AST" };  // only covering limited zones
int zone;
int zoneIndex;  // 0 to 13
unsigned long lastTime = 0;
int lastDay = 0;                        // used to not display unchanged date every second
unsigned long longTimeMilli = 0;        // if > 5 minutes in options, exit options

unsigned long currentMilli = 0;         // used to attempt accurate 100ms Loop timer
bool optionsStarted = false;
unsigned long optionsTimeout = 0;
int loopDurationMS = 100;               // planned loop duration, but is longer for many actions (i.e. graphics display update)

unsigned long lastMilli = 0;

#define logSize 32
time_t actionLog[logSize] = { 0 };      // type of entry (i.e. LOG_IN, etc.), a long on ESP32
int actionType[logSize]   = { 0 };      // array of action times in UTC time
int trendInside[logSize]  = { 0 };      // array of trend values used to determine if inside or out
int trendOutside[logSize] = { 0 };
struct tm* logTime;
int currentLogPtr = 0;                  // last log entry
int logPage = 0;                        // which page to display (4 entries per page)
#define LOG_UNUSED 0                    // types of log entries stored in actionLog
#define LOG_READY 1
#define LOG_IN 2
#define LOG_OUT 3
#define LOG_BUTTON 4                    // debug only

#define SENSOR_ACTIVE 1
#define SENSOR_INACTIVE 0
#define SENSOR_NOT_TRIPPED 0
#define SENSOR_TRIPPED 1
int lastSensorStateFront = SENSOR_INACTIVE;
int currentSensorStateFront = SENSOR_INACTIVE;
long activeSensorTimeFront = 0;
long inactiveSensorTimeFront = 0;
int sensorActionFront = SENSOR_NOT_TRIPPED;
int sensorThresholdCount = 0;
int maxSensorThreshold = 300;         // max value in mm

// Sensor Weighting Process
// This deals with the erratic values that can occur with pets not moving perfectly through the beams
// by tracking the 4 sensor values over the duration any sensors are triggered.
// bit 0 - Rear (outside side); bit 1 - Near Rear; bit 2 - Near Front; bit 3 - Front (inside side)
int sensorWeights[16] = { 0, 1, 0, 2, 0, 0, 0, 3, 7, 0, 0, 0, 6, 0, 5, 4 };
int sensorTrendInside = 0;
int sensorTrendOutside = 0;
#define sensorTrendShift 2      // This values adds weight to the trend outside coming in.  A zero value adds no weight.
                                // this might be different for other pet/door/positions. 
                                // With zero, we were getting too many "Now Outside" triggers when the pet had come in!
int eventsTraced = 0;
int sensorBitsLast = 0;
bool trendSet = false;
String trend = "";



// button press states
#define NONE 0
#define SHORT 1
#define LONG 2
#define VERYLONG 3
#define BUTTON0 0  // button pin
#define DOWN 0     // button position pressed
#define UP 1       // button position released
int lastButtonState = UP;
int currentButtonState = UP;
long pressedTime = 0;
long releasedTime = 0;

int buttonAction = NONE;
String debugLastAction = "";

// base64 images for web
String Pet_Outside;         
String Pet_Inside;
String Pet_Ready;
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
void loop() {
  // check for button press and sensor changes every 100 mS

  // read the ButtonState of the button (Down=0, Up=1)
  buttonAction = NONE;
  currentButtonState = digitalRead(BUTTON0);
  if (lastButtonState != currentButtonState) {
    if (lastButtonState == UP && currentButtonState == DOWN)  // button is pressed
      pressedTime = millis();
    else if (lastButtonState == DOWN && currentButtonState == UP) {  // button is released
      releasedTime = millis();

      long pressDuration = releasedTime - pressedTime;
      lastState = state;
      if ((pressDuration < 700) && (pressDuration > 100)) {  // ignore very short presses
        buttonAction = SHORT;
        // debug
        debugLastAction = "Button short";
      }
      if (pressDuration >= 5000) {  // 5 seconds
        buttonAction = VERYLONG;
        debugLastAction = "Button very long";
      } else if (pressDuration >= 800) {
        buttonAction = LONG;
        debugLastAction = "Button long";
      }
    }
    lastButtonState = currentButtonState;
  }

  // check status change from sensor and update in/out status

  // process actions
  if (state == READY) {
    frameReady();
  } else if (state == INSIDE) {
    frameInside();
  } else if (state == OUTSIDE) {
    frameOutside();
  } else if (state == LOG) {      // each short press rotates through these frames
    frameLog();
  } else if (state == WIFI) {
    frameWiFi();
  } else if (state == SENSOR) {
    frameSensor();
  } else if (state == HOURS) {
    frameHours();
  } else if (state == GMTADJ) {
    frameGmtAdj();
  } else if (state == COLOR) {
    frameColor();
  } else if (state == PET_IMAGES) {
    framePetImages();
  } else if (state == ABOUT) {
    frameAbout();
  } else if (state == ERROR) {        // rest of these frames are special cases  
    frameError();
  } else if (state == WIFI_RESET) {
    frameWiFiReset();
  } else if (state == WIFI_SETUP) {
    frameWiFiSetup();
  } else if (state == TRACE) {
    frameTrace();
  }

  if (state < LOG) processWebRequest();       // if requested, display web page only if not in menus
  if (webIndicatorTimeout > 0) {
    webIndicatorTimeout --;
    if (webIndicatorTimeout == 0) lcd.fillCircle(LCD_WIDTH-3, LCD_HEIGHT-3, 2, black); // turn off indicator
  }
  // try to wait the delay for each loop (unless code takes longer during a loop)
  currentMilli = millis();
  if ((currentMilli - lastMilli) < loopDurationMS) {
    delay(loopDurationMS - (currentMilli - lastMilli));
  } else if (debug) {
    Serial.print("Loop took ms: ");
    Serial.println(currentMilli - lastMilli);
    // no additional delay (ran out of time, as happens when larger graphics displayed)
  }
  lastMilli = millis();

  // if options take longer than 5 minutes, exit options
  if (optionsStarted && (optionsTimeout + 300000 < lastMilli)) {
    optionsStarted = false;
    state = NOMORE;
    exitState();
  }
}

// ============================ Functions ===================================

void frameReady() {
  if (frameFirstTime) {
    displayInOutHeading(123, Cat_Ready_123x170_gif, Dog_Ready_123x170_gif);
    displayNowAction = "Ready";
    displayCurrentAction = "Awaiting</br>Movement";
    webColor = magenta;
    displayCenter(18, magenta, center, 58, displayNowAction.c_str());
    if (sensorValid) {
      displayCenter(12, medmagenta, center, 90, "Awaiting");
      displayCenter(12, medmagenta, center, 112, "Movement");
      displayPriorAction = "";
    } else {
      displayCenter(12, red, center, 90, "Sensor");
      displayCenter(12, red, center, 112, "Inactive");
      displayPriorAction = "Sensor Inactive";
    }
      
    displayCenter(9, grey, center, 150, "Short press - options");
    for (int i = 0; i < 4; i++) {
      indicatorOn[i] = false;
    }
    sensorAllOn = false;

    // save current time to log
    time(&now);
    localtime_r(&now, &timeinfo);
    if (timeinfo.tm_year > 124) {  // 1900+124 = 2024 (if year is 2024 or older, time is invalid)
      currentLogPtr = (currentLogPtr + 1) % logSize;
      actionType[currentLogPtr] = LOG_READY;
      actionLog[currentLogPtr] = now;
      trendInside[currentLogPtr] = 0;
      trendOutside[currentLogPtr] = 0;
    }
  }
  setState();
}

void frameInside() {
  if (frameFirstTime) {
    displayInOutHeading(123, Cat_Inside_123x170_gif, Dog_Inside_123x170_gif);
    displayNowAction = "Now Inside";
    webColor = insideColor;
    displayCenter(18, insideColor, center, 54, displayNowAction.c_str());
    for (int i = 0; i < 4; i++) {
      indicatorOn[i] = false;
    }
    sensorAllOn = false;

    // current entry should be LOG_IN
    int tempPtr = InOutLogPtr(0);  // get the newest in/out log ptr
    if (tempPtr != -1) {
      if (actionType[tempPtr] == LOG_IN) {  // should always be true!
        time_t raw_time = actionLog[tempPtr];
        struct tm* logTime = localtime(&raw_time);
        if (logTime != nullptr) {
          displayCurrentActionHead = "Returned at";
          displayCenter(9, grey, center, 74, displayCurrentActionHead.c_str());
          displayCurrentAction = convertTime(logTime->tm_hour, logTime->tm_min, -1);
          displayCenter(18, insideColorMed, center, 108, displayCurrentAction.c_str());
        }
      }

      int priorLogPtr = InOutLogPtr(1);  // get the next to newest in/out log ptr
      displayPriorAction = "";
      displayPercentAction = "";
      if (priorLogPtr != -1) {
        if (actionType[priorLogPtr] == LOG_OUT) {
          displayPriorAction = "Prior out at ";  // normal
        } else if (actionType[priorLogPtr] == LOG_IN) {
          displayPriorAction = "Prior in at ";  // unusal event, two in transitions in a row - maybe multiple pets or used another door to go out
        }
        if (displayPriorAction != "") {
          time_t prior_time = actionLog[priorLogPtr];
          struct tm* logTime = localtime(&prior_time);
          if (logTime != nullptr) {
            displayPriorAction += convertTime(logTime->tm_hour, logTime->tm_min, -1);
            displayCenter(9, grey, center, 130, displayPriorAction.c_str());
          }

          // scan log to get percentage time in vs. out
          int percentOutside = percentInOut();
          if (percentOutside != -1) {
            char tempText[30];
            sprintf(tempText, "Time outside %d%%", percentOutside);
            displayPercentAction = String(tempText);
            displayCenter(9, grey, center, 153, tempText);
          }
        }
      }
    }
  }
  setState();
}

void frameOutside() {
  if (frameFirstTime) {
    displayInOutHeading(123, Cat_Outside_123x170_gif, Dog_Outside_123x170_gif);
    displayNowAction = "Now Outside";
    webColor = outsideColor;
    displayCenter(18, outsideColor, center, 54, displayNowAction.c_str());
    for (int i = 0; i < 4; i++) {
      indicatorOn[i] = false;
    }
    sensorAllOn = false;

    // current entry should be LOG_OUT
    int tempPtr = InOutLogPtr(0);  // get the newest in/out log ptr
    if (tempPtr != -1) {
      if (actionType[tempPtr] == LOG_OUT) {  // should always be true!
        time_t raw_time = actionLog[tempPtr];
        struct tm* logTime = localtime(&raw_time);
        if (logTime != nullptr) {
          displayCurrentActionHead = "Left at";
          displayCenter(9, grey, center, 74, displayCurrentActionHead.c_str());
          displayCurrentAction = convertTime(logTime->tm_hour, logTime->tm_min, -1);
          displayCenter(18, outsideColorMed, center, 108, displayCurrentAction.c_str());
        }
      }

      int priorLogPtr = InOutLogPtr(1);  // get the next to newest in/out log ptr
      displayPriorAction = "";
      displayPercentAction = "";
      if (priorLogPtr != -1) {
        if (actionType[priorLogPtr] == LOG_OUT) {
          displayPriorAction = "Prior out at ";  // unusal event, two out transistions in a row - maybe multiple pets or used another door
        } else if (actionType[priorLogPtr] == LOG_IN) {
          displayPriorAction = "Prior in at ";  // normal
        }
        if (displayPriorAction != "") {
          time_t prior_time = actionLog[priorLogPtr];
          struct tm* logTime = localtime(&prior_time);
          if (logTime != nullptr) {
            displayPriorAction += convertTime(logTime->tm_hour, logTime->tm_min, -1);
            displayCenter(9, grey, center, 130, displayPriorAction.c_str());
          }

          // scan log to get percentage time in vs. out
          int percentOutside = percentInOut();
          if (percentOutside != -1) {
            char tempText[30];
            sprintf(tempText, "Time outside %d%%", percentOutside);
            displayPercentAction = String(tempText);
            displayCenter(9, grey, center, 153, tempText);
          }
        }
      }
    }
  }
  setState();
}
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

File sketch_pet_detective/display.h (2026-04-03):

/*  Pet Detective, by FAQware

LCD Display related includes, defines, variables and code

20-Jan-2026 (c) FAQware

*/

#include "ColorFormat.h"
// various display routines

#include <Adafruit_GFX.h>    // Importing the Adafruit_GFX library
#include <Adafruit_ST7789.h> // Import the Adafruit_ST7789 library
#include <Fonts/FreeSans9pt7b.h>
#include <Fonts/FreeSans12pt7b.h>
#include <Fonts/FreeSans18pt7b.h>
#include <Fonts/FreeMono9pt7b.h>
#include "GIF_general.h"     // logos and indicators
#include "GIF_cats.h"        // Cat images
#include "GIF_dogs.h"        // Dog images

//Define the size of the screen
#define LCD_HEIGHT  170     // after rotation!
#define LCD_WIDTH 320       // after rotation!
//Define the pins of the ESP32 connected to the LCD
#define LCD_MOSI 23         // SDA Pin on ESP32 D23
#define LCD_SCLK 18         // SCL Pin on ESP32 D18
#define LCD_CS   15         // Chip select control pin on ESP32 D15
#define LCD_DC    2         // Data Command control pin on ESP32 D2
#define LCD_RST   4         // Reset pin (could connect to RST pin) on ESP32 D4
#define LCD_BLK   32        // Black Light Pin on ESP32 D32
//Create the Adafruit_ST7789 object
Adafruit_ST7789 lcd = Adafruit_ST7789(LCD_CS, LCD_DC, LCD_RST);


void displayLeftClear(int font, int color, int x, int y, int width, const char *buf);
void displayLeft(int font, int color, int x, int y, const char *buf); 
void displayCenter(int font, int color, int x, int y, const char *buf);
void displayText(int color, int x, int y, const char *buf);
void displayChoice(int color, int x, int y, int val, const char *bufFalse, const char *bufTrue);
void displayInOutHeading(int width, const uint8_t *buf);
void displayHeading(const char *lastLine, const char *buf);
void displayRightClear(int font, int color, int x, int y, int width, const char *buf);
void ShowGifCatDog(int16_t x_loc, int16_t y_loc, const uint8_t *catName, const uint8_t *dogName);
void ShowGif (int16_t x_loc, int16_t y_loc, const uint8_t *filename);
void displayZone();
void setTextColorLCD(int color565);


#define CATS 0
#define DOGS 1
int petImages = CATS;
bool lcdDim = false;    // set to true for dimmer colors
int percentIncrease = 40;

String convertRgb565ToRgb888(int color565);

//------------------ Colors for LCD -------------------------------
int black       = 0;
int red         = lcd.color565(220, 0, 0);
int magenta     = lcd.color565(233, 0, 210);
int medmagenta  = lcd.color565(192, 0, 173);
int berry       = lcd.color565(84, 87, 179);  // blue-purple
int lilac       = lcd.color565(107, 111, 232);
int purple      = lcd.color565(128, 0, 255);
int babyblue    = lcd.color565(129, 174, 242);
int medblue     = lcd.color565(108, 148, 209);
int blue        = lcd.color565(0, 0, 255);
int cyan        = lcd.color565(0, 255, 255);
int green       = lcd.color565(0, 215, 36);
int medgreen    = lcd.color565(0, 178, 24);
int lime        = lcd.color565(128, 255, 0);
int yellow      = lcd.color565(240, 240, 0);
int amber       = lcd.color565(255, 180, 0);
int medamber    = lcd.color565(194, 143, 0);
int grey        = lcd.color565(140, 140, 140);
int darkgrey    = lcd.color565(25, 25, 25);
int white       = lcd.color565(255, 255, 255);

int insideColor = amber;
int insideColorMed = medamber;
int outsideColor = green;
int outsideColorMed = medgreen;
int colorType = 0;    // one of 6 color combinations

// psoitioning of items
int center  = 112;    // center point for most text when image on side (IN/OUT/READY)
int heading = center - 122/2 + 5;   // Secondary pet detective centering   
bool frameFirstTime = true;   // within each frame, what is static when firstTime


#define STARTUP      0    // action states
#define READY        1
#define OUTSIDE      2
#define INSIDE       3

#define LOG          4    // sequencial menu items
#define WIFI         5
#define SENSOR       6
#define HOURS        7
#define GMTADJ       8
#define COLOR        9
#define PET_IMAGES  10
#define ABOUT       11
#define NOMORE      12

#define ERROR       13    // stand-alone functions
#define WIFI_RESET  14 
#define WIFI_SETUP  15 
#define TRACE       16

int state      = 0;
int priorState = 0;           //  used to skip repaint of some graphics when same as before
int lastState  = 0;
int frameCounter    = 0;      // within each frame, counter for refresh of part of display

// Display "Pet Detective" graphic and GIF image on right
void displayInOutHeading(int width, const uint8_t *catbuf, const uint8_t *dogbuf) {
  frameFirstTime = false;
  if ((priorState == READY) || (priorState == INSIDE) || (priorState == OUTSIDE)) {
    // no need for Pet Detective graphic - only blackout other areas
    lcd.fillRect(0, 0, 10, 22, black);    // clear indicator area
    lcd.fillRect(0, 22, LCD_WIDTH-90, LCD_HEIGHT-22, black);    // clear only text area, not graphics
  } else {
    lcd.fillScreen(black);
    ShowGif(center-122/2, 2, Pet_Detective_Text_122x17_gif);
  }
  ShowGifCatDog(LCD_WIDTH-width, 0, catbuf, dogbuf);
}



// Display Title and "Pet Detective" graphic, and bottom line action
// Lastline values: LINENEXT, LINEEND, or LINENONE
void displayHeading(const char *lastLine, const char *buf) {
  frameFirstTime = false;
  if ((priorState == READY) || (priorState == INSIDE) || (priorState == OUTSIDE) || (state == WIFI_SETUP) || (state == ERROR)) {
    lcd.fillScreen(black);
    ShowGif(LCD_WIDTH-124, 2, Pet_Detective_Text_122x17_gif);
  } else {
    // no need for Pet Detective graphic - only blackout other areas
    lcd.fillRect(0, 0, LCD_WIDTH-122, 26, black);    // clear only text area, not graphics
    lcd.fillRect(0, 26, LCD_WIDTH, LCD_HEIGHT-26, black);    // clear only text area, not graphics
  }
  displayLeft(18, purple, 2, 26, buf);

  if (strlen(lastLine) != 0) {
    displayLeft(9, grey, 0, 160, "Short press for ");
    lcd.print(lastLine);
  }

}


// Set one of three font sizes
void displaySetFont(int font) {
  if (font == 18) {
    lcd.setFont(&FreeSans18pt7b);
  } else if (font == 12) {
    lcd.setFont(&FreeSans12pt7b);
  } else if (font == 9) {
    lcd.setFont(&FreeSans9pt7b);
  } else {
    lcd.setFont(&FreeMono9pt7b);    // -9
  }
}

// Display text left aligned, but clear width first (untested for 18pt font)
void displayLeftClear(int font, int color, int x, int y, int width, const char *buf) {
  int16_t x1, y1;
  uint16_t w, h;
  uint16_t adj = 0;
  setTextColorLCD(color);
  displaySetFont(font);
  if (font > 9) adj = 5;
  lcd.getTextBounds(buf, 0, 0, &x1, &y1, &w, &h);
  lcd.fillRect(x, y-12-adj, width-1, h+3+adj, black);
  lcd.setCursor(x, y);
  lcd.print(buf);
}

// display text left aligned
void displayLeft(int font, int color, int x, int y, const char *buf) {
  displaySetFont(font);
  setTextColorLCD(color);
  lcd.setCursor(x, y);
  lcd.print(buf);
}
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

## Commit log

2026-03-04 Delete 3D STL Print Files/Pet Detector Polycarbonate Template V3.stl
    Wrong file included.
    [Pet Detector Polycarbonate Template V3.stl]
2026-03-04 Delete 3D STL Print Files/Pet Detective Blackout Frame V3.stl
    Old version should not have been included
    [Pet Detective Blackout Frame V3.stl]
2026-03-05 Add files via upload
    Pet Detective features, parts, assembly, and operation.
2026-04-03 Add files via upload
    Design improvements
    Select from Cat or Dog images
    Better handling if sensor disconnected
    Improved web page status
